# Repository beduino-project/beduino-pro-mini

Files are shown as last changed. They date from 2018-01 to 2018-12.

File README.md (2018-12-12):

Beduino Pro Mini
================

The Beduino Pro Mini is a prototyping board based on the NXP MKW41Z SoC:

* ARM Cortex-M0+ CPU
* 64/128 KB RAM
* 256/512 KB flash
* 2.4 GHz transceiver supporting Bluetooth Low Energy and IEEE 802.15.4
* AES-128 Hardware Accelerator
* True Random Number Generator

In addition to the SoC, the board features the following:

* 2.4 GHz trace antenna
* LDO voltage regulator for 5V supply
* The necessary oscillators and passive components
* Two LEDs (red and green)
* Reset button

The board layout also includes a DIPDAP programmer, which can be
detached from the Beduino Pro Mini (using a fine saw or a dremel tool)
and later reconnected using the usual seven-pin DIPDAP header.
The programmer features the following:

* USB connection
* Flashing and debugging of the MKW41Z using SWD
* Fully supported in OpenOCD
* USB-to-Serial adapter
* Powering of Beduino Pro Mini over USB

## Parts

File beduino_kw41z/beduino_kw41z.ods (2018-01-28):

Mouser | Tqnty | Ref | Qnty | Spare | Spconst | Value | Cmp name | Footprint | Description | Vendor
449-LFXTAL055295REEL | 19 | Y1, | 1 |  | 2 | 12MHz | Crystal_GND24 | Crystals:Crystal_SMD_3225-4pin_3.2x2.5mm | Four pin crystal (GND on pins 2 and 4), e.g. in SMD package
579-TC1017-3.3VLTTR | 36 | U1, U3, | 2 |  | 2 | TC1017 | TC1017 | TO_SOT_Packages_SMD:SOT-23-5 | 150mA Low Dropout Regulator with ERROR output in 5-Pin SOT-23 package
581-ST2012SB32E0HPWB | 18 | Y3, | 1 |  | 1 | 32KHz | Crystal | Crystals:Crystal_SMD_2012-2pin_2.0x1.2mm | Two pin crystal
603-RC0603JR-0710KL | 61 | R5, R4, R16, | 3 |  | 10 | 10k | R | Resistors_SMD:R_0603 | Resistor
603-RC0603JR-071K5L | 27 | R3, | 1 |  | 10 | 1k5 | R | Resistors_SMD:R_0603 | Resistor
603-RC0603JR-0733RL | 44 | R1, R2, | 2 |  | 10 | 33 | R | Resistors_SMD:R_0603 | Resistor
603-RC0603JR-07470RL | 180 | R9, R10, R11, R12, R13, R6, R7, R8, R14, R15, | 10 |  | 10 | 470 | R | Resistors_SMD:R_0603 | Resistor
604-APT1608EC | 44 | D2, D5, | 2 |  | 10 | Red | LED | LEDs:LED_0603 | LED generic
604-APT1608SGC | 44 | D4, D6, | 2 |  | 10 | Green | LED | LEDs:LED_0603 | LED generic
604-APT1608SYCK | 27 | D3, | 1 |  | 10 | Yellow | LED | LEDs:LED_0603 | LED generic
611-KMR621NGLFS | 35 | SW1, SW2, | 2 |  | 1 | SW_Push | SW_Push | button:SW_SPST_KMR6 | Push button switch, generic, two pins
726-BAT60AE6327HTSA1 | 53 | D1, D7, D8, | 3 |  | 2 | BAT60A | D_Schottky | Diodes_SMD:D_SOD-323 | Schottky diode
726-BSS84PH6327XTSA2 | 22 | Q1, | 1 |  | 5 | Q_PMOS_SGD | Q_PMOS_SGD | TO_SOT_Packages_SMD:SOT-23 | Transistor P-MOSFET with substrate diode (general)
771-LPC11U35FHI33501 | 17 | U2, | 1 |  |  | LPC11U35FHI33-501 | LPC11U35FHI33-501 | Housings_DFN_QFN:QFN-32-1EP_5x5mm_Pitch0.5mm
774-402F32011CAR | 18 | Y2, | 1 |  | 1 | 32MHz | Crystal_GND24 | Crystals:Crystal_SMD_2016-4pin_2.0x1.6mm | Four pin crystal (GND on pins 2 and 4), e.g. in SMD package
798-ZX62D-B-5PA830 | 17 | J1, | 1 |  |  | USB_OTG | USB_OTG | Connectors:USB_Micro-B | USB mini/micro connector
80-C0603C104K8RAC | 61 | C6, C8, C13, | 3 |  | 10 | 100n | C | Capacitors_SMD:C_0603 | Unpolarized capacitor
80-C0603C105Z8V | 44 | C1, C9, | 2 |  | 10 | 1u | C | Capacitors_SMD:C_0603 | Unpolarized capacitor
80-C0603C180J5G | 44 | C5, C7, | 2 |  | 10 | 18p | C_Small | Capacitors_SMD:C_0603 | Unpolarized capacitor
81-GRM1555C1HR70CA1D | 44 | C10, C11, | 2 |  | 10 | 0.7p | C | Capacitors_SMD:C_0402 | Unpolarized capacitor
81-GRM155R61H104KE9D | 78 | C14, C15, C16, C17, | 4 |  | 10 | 100n | C | Capacitors_SMD:C_0402 | Unpolarized capacitor
81-LQG15HZ5N1S02D | 27 | L1, | 1 |  | 10 | 5.1n | L | Inductors_SMD:L_0402 | Inductor
841-MKW41Z256VHT4 | 17 | U5, | 1 |  |  | MKW41Z | MKW41Z | Housings_DFN_QFN:QFN-48-1EP_7x7mm_Pitch0.5mm | NXP MKW41Z Microcontroller
963-JMK107ABJ106MA-T | 44 | C4, C12, | 2 |  | 10 | 10u | C | Capacitors_SMD:C_0603 | Unpolarized capacitor
 | 34 | J2, J3, | 2 |  |  | Conn_01x07 | Conn_01x07 | Pin_Headers:Pin_Header_Straight_1x07_Pitch2.54mm | Generic connector, single row, 01x07
 | 17 | U4, | 1 |  |  | Module_CONN | Module_CONN | Arduino_Mini

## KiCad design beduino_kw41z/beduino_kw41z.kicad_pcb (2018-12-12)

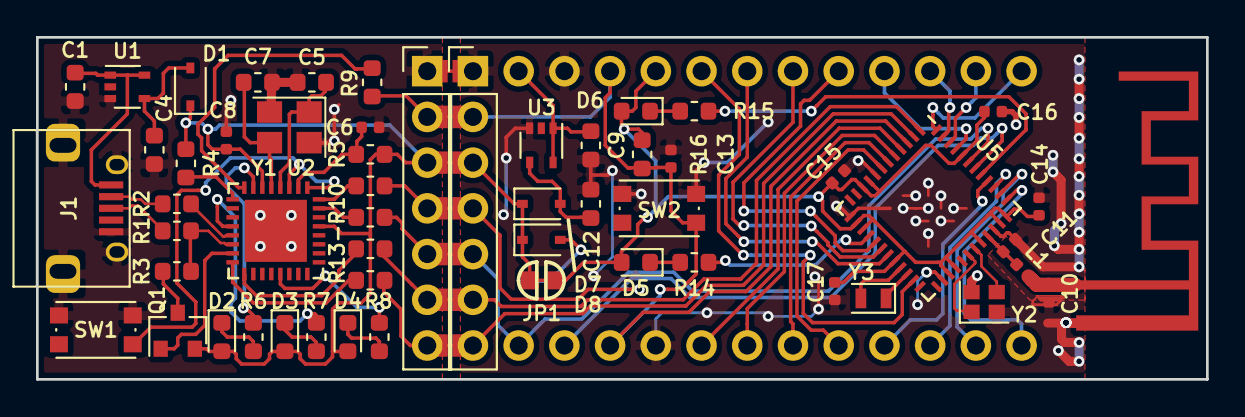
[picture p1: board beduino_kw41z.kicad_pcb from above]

Board: 2 copper layers, 65.0 x 19.0 mm, 57 parts (1 on the bottom side), 60 nets.

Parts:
ANT1: SWRA117D
BT1: Battery_Cell; Keystone_1058_1x2032-CoinCell
C1, C9: 1u; C_0603_1608Metric
C4, C12: 10u; C_0603_1608Metric
C5, C7: 18p; C_0603_1608Metric
C6, C8, C13, C14, C15, C16, C17: 100n; C_0402_1005Metric
C10, C11: 0.7p; C_0402_1005Metric
D1, D7, D8: BAT60A; D_SOD-323
D2, D5: Red; LED_0603_1608Metric
D3: Yellow; LED_0603_1608Metric
D4, D6: Green; LED_0603_1608Metric
J1: USB_OTG; USB_Micro-B
J2, J3: Conn_01x07; Pin_Header_Straight_1x07_Pitch2.54mm
JP1: Power; SOLDER-JUMPER_1-WAY
L1: 5.1n; L_0402_1005Metric
Q1: Q_PMOS_GSD; SOT-23
R1, R2: 33; R_0603_1608Metric
R3: 1k5; R_0603_1608Metric
R4, R5, R16: 10k; R_0603_1608Metric
R6, R7, R8, R9, R10, R11, R13, R13-R10, R14, R15: 470; R_0603_1608Metric
SW1: SW_Push; SW_SPST_KMR2
SW2: Reset; SW_SPST_KMR2
U1, U3: TC1017; SOT-353_SC-70-5
U2: LPC11U35FHI33-501; QFN-32-1EP_5x5mm_P0.5mm_EP3.45x3.45mm
U4: Module_CONN; Arduino_Mini
U5: MKW41Z; QFN-48-1EP_7x7mm_P0.5mm_EP5.15x5.15mm
Y1: 12MHz; Crystal_SMD_3225-4Pin_3.2x2.5mm
Y2: 32MHz; Crystal_SMD_2016-4Pin_2.0x1.6mm
Y3: 32KHz; Crystal_SMD_2012-2Pin_2.0x1.2mm

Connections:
+3V3: C8.1, C14.1, C15.1, C16.1, C17.1, D1.1, D2.2, D3.2, D4.2, D5.2, D6.2, D7.1, D8.1, J2.3, J3.3, JP1.1, JP1.2, Q1.2, R4.1, R5.2, R16.1, U2.6, U2.29, U4.21, U5.9, U5.10, U5.14, U5.15, U5.20, U5.27, U5.28, U5.32, U5.35, U5.36, U5.44
/DIPDAP/TGT_NRESET: C13.1, J2.2, J3.2, R9.1, R16.2, SW2.2, U4.3, U4.22, U5.3
/DIPDAP/TGT_RX: J2.4, J3.4, R10.1, U4.2, U5.42
/DIPDAP/TGT_SWCLK: J2.7, J3.7, R13.1, U5.2
/DIPDAP/TGT_SWDIO: J2.6, J3.6, R13-R10.1, U5.1
/DIPDAP/TGT_TX: J2.5, J3.5, R11.1, U4.1, U5.43
/KW41Z/A0: U4.17, U5.17
/KW41Z/A1: U4.18, U5.18
/KW41Z/A2: U4.19, U5.19
/KW41Z/A3: U4.20, U5.23
/KW41Z/ANT: C11.1, L1.1, U5.33
/KW41Z/D2: U4.5, U5.4
/KW41Z/D3: U4.6, U5.5
/KW41Z/D4: U4.7, U5.6
/KW41Z/D5: U4.8, U5.7
/KW41Z/D6: U4.9, U5.40
/KW41Z/D9: U4.12, U5.37
/KW41Z/D10: U4.13, U5.48
/KW41Z/LED_Green: R15.1, U5.41
/KW41Z/LED_Red: R14.1, U5.16
/KW41Z/MISO: U4.15, U5.47
/KW41Z/MOSI: U4.14, U5.46
/KW41Z/SCK: U4.16, U5.45
/KW41Z/SCL: U4.11, U5.38
/KW41Z/SDA: U4.10, U5.39
GND: ANT1.2, BT1.2, C1.2, C4.2, C5.2, C6.2, C7.2, C8.2, C9.2, C10.2, C11.2, C12.2, C13.2, C14.2, C15.2, C16.2, C17.2, J1.5, J1.6, J2.1, J3.1, SW1.1, SW2.1, U1.3, U2.33, U3.3, U4.4, U4.23, U5.8, U5.13, U5.26, U5.34, Y1.2, Y1.4, Y2.2, Y2.4
unnamed: ANT1.1, C10.1, L1.2
unnamed: BT1.1, D8.2
unnamed: R2.1, U2.13
unnamed: R1.1, R3.1, U2.14
unnamed: C4.1, D1.2, U1.4
unnamed: C5.1, U2.4, Y1.1
unnamed: C6.1, R5.1, U2.2
unnamed: C7.1, U2.5, Y1.3
unnamed: C12.1, D7.2, U3.4
unnamed: D2.1, R6.1
unnamed: D3.1, R7.1
unnamed: D4.1, R8.1
unnamed: D5.1, R14.2
unnamed: D6.1, R15.2
unnamed: J1.2, R2.2
unnamed: J1.3, R1.2
unnamed: Q1.1, U2.15
unnamed: Q1.3, R3.2
unnamed: R4.2, U2.9
unnamed: R6.2, U2.7
unnamed: R7.2, U2.12
unnamed: R8.2, U2.21
unnamed: R9.2, U2.8
unnamed: R10.2, U2.32
unnamed: R11.2, U2.31
unnamed: R13-R10.2, U2.17
unnamed: R13.2, U2.16
unnamed: SW1.2, U2.1, U2.3
unnamed: U5.21, Y3.2
unnamed: U5.22, Y3.1
unnamed: U5.30, Y2.1
unnamed: U5.31, Y2.3
VBUS: C1.1, J1.1, U1.1, U1.5
VCC: C9.1, U3.1, U3.5, U4.24

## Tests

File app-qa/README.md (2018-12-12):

This is an application for [RIOT][] that helps with post-production
quality assurance.

Documentation for this has not yet been written, sadly.
I promise to write documentation as soon as I know of someone ordering
these boards.

[RIOT]: http://riot-os.org/
	"The friendly Operating System for the Internet of Things."

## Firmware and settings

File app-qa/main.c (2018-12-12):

/*
 * Copyright (C) 2018 Tristan Bruns
 *
 * Licensed under the Apache License, Version 2.0 (the "License");
 * you may not use this file except in compliance with the License.
 * You may obtain a copy of the License at
 *
 *     http://www.apache.org/licenses/LICENSE-2.0
 *
 * Unless required by applicable law or agreed to in writing, software
 * distributed under the License is distributed on an "AS IS" BASIS,
 * WITHOUT WARRANTIES OR CONDITIONS OF ANY KIND, either express or implied.
 * See the License for the specific language governing permissions and
 * limitations under the License.
 */

#include <stdio.h>

#include "board.h"
#include "periph/gpio.h"

#include "xtimer.h"

gpio_t gpios[] = {
  // back row, left to right
  GPIO_PIN(PORT_B, 18),
  GPIO_PIN(PORT_B,  3),
  GPIO_PIN(PORT_B,  2),
  GPIO_PIN(PORT_B,  1),
  GPIO_PIN(PORT_C, 16),
  GPIO_PIN(PORT_C, 17),
  GPIO_PIN(PORT_C, 18),
  GPIO_PIN(PORT_C, 19),
  // front row, left to right
  GPIO_PIN(PORT_A, 16),
  GPIO_PIN(PORT_A, 17),
  GPIO_PIN(PORT_A, 18),
  GPIO_PIN(PORT_A, 19),
  GPIO_PIN(PORT_C, 4),
  GPIO_PIN(PORT_C, 3),
  GPIO_PIN(PORT_C, 2),
  GPIO_PIN(PORT_C, 1),
};
#define NUM_GPIOS (sizeof gpios / sizeof gpios[0])

#ifdef CLOCK_CORECLOCK
#define DELAY_SHORT         (CLOCK_CORECLOCK / 50)
#else
#define DELAY_SHORT         (500000UL)
#endif

void dumb_delay(uint32_t delay)
{
    for (uint32_t i = 0; i < delay; i++) {
        __asm__("nop");
    }
}

//! Signal test FAIL to human
void fail(void)
{
    while (1) {
        LED0_TOGGLE;
        dumb_delay(DELAY_SHORT);
        //xtimer_usleep(100);
    }
}

//! Signal test pass to human
void pass(void)
{
    while (1) {
        LED1_TOGGLE;
        dumb_delay(DELAY_SHORT);
    }
}

//! Flash LEDs for testing
void led_test(void)
{
    int i;

    for (i = 0; i < 10; i++) {
        LED0_TOGGLE;
        LED1_TOGGLE;
        dumb_delay(DELAY_SHORT);
    }
}

//! Check for ground shorts
void check_short_gnd(void)
{
    unsigned int i;

    for (i = 0; i < NUM_GPIOS; i++)
    {
        gpio_init(gpios[i], GPIO_IN_PU);
    }
    dumb_delay(DELAY_SHORT); // allow for pin capacitance
    for (i = 0; i < NUM_GPIOS; i++)
    {
        if (!gpio_read(gpios[i]))
            fail();
    }
}

//! Check for supply shorts
void check_short_vcc(void)
{
    unsigned int i;

    for (i = 0; i < NUM_GPIOS; i++)
    {
        gpio_init(gpios[i], GPIO_IN_PD);
    }
    dumb_delay(DELAY_SHORT); // allow for pin capacitance
    for (i = 0; i < NUM_GPIOS; i++)
    {
        if (gpio_read(gpios[i]))
            fail();
    }
}

//! Check for shorts between gpios
// This test configures GPIOs as outputs. Try to make sure this is safe
// beforehand!
void check_short_gpio(void)
{
    unsigned int i, j;

    // configure all GPIOs as inputs with pulldown
    for (i = 0; i < NUM_GPIOS; i++)
    {
        gpio_init(gpios[i], GPIO_IN_PD);
    }

    // drive each pin HIGH and check all other pins are still LOW
    for (i = 0; i < NUM_GPIOS; i++)
    {
        gpio_init(gpios[i], GPIO_OUT);
        gpio_set(gpios[i]);
        dumb_delay(DELAY_SHORT); // allow for pin capacitance

        for (j = 0; j < NUM_GPIOS; j++) {
            if (j != i && gpio_read(gpios[j])) {
                // stop driving the pin because it might be shorted to
                // other stuff, too. but use a pullup so the pin can be
                // found with a multimeter if it isn't.
                gpio_init(gpios[i], GPIO_IN_PU);

                fail();
            }
        }
        gpio_init(gpios[i], GPIO_IN_PD);
    }
}

//! Check for unconnected pads
// This needs user interaction.
void check_unconnected(void)
{
    // what am I even doing?
    unsigned int i;
    char state[NUM_GPIOS + 1];

    state[NUM_GPIOS] = '\0'; // tease the compiler

    for (i = 0; i < NUM_GPIOS; i++)
    {
        state[i] = '?';
        gpio_init(gpios[i], GPIO_IN_PD);
    }
    dumb_delay(DELAY_SHORT); // allow for pin capacitance

    puts("Gently pull up all GPIOs with TODO \\Ohms");
    printf("Status: %s\n", state);

    int cont = 1;
    while (cont) {
        cont = 0;
        for (i = 0; i < NUM_GPIOS; i++)
        {
            if (state[i] != '?')
                continue;
            cont = 1;

            if (gpio_read(gpios[i])) {
                state[i] = '+';
                printf("Status: %s\n", state);
            }
        }
    }

    puts("\nPass.");
}

void check_xtimer(void)
{
    uint32_t diff;
    volatile xtimer_ticks32_t a, b;

    a = xtimer_now();
    dumb_delay(DELAY_SHORT);
    b = xtimer_now();

    diff = xtimer_usec_from_ticks(xtimer_diff(b, a));

    if (diff < 139587 - 1000 || 139587 + 1000 < diff) {
        printf("xtimer test failed: %lu\n", diff);
        fail();
    }
}

int main(void)
{
    puts("Welcome to Beduino Pro Mini QA test app");

    led_test();
    check_xtimer();
    check_short_gnd();
    check_short_vcc();
    check_short_gpio();
    check_unconnected();

    pass();

    return 0;
}

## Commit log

2017-12-03 Add gitignore for kicad files
2017-12-03 Add schematic files for the pcb and the created libraries.
    [beduino_kw41z.kicad_pcb, beduino_kw41z.sch, dipdap.sch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]
2017-12-03 Add antenna libraries and antenna hardware design.
2017-12-04 Add jumper into the power trace.
    This makes it possible to measure the current used by the module.
    [kw41z.sch]
2017-12-04 Change 32MHz Crystal to a 4 pin type.
    [kw41z.sch]
2017-12-12 Update schematic for new KiCAD version.
    Also add some components.
    [beduino_kw41z.sch, dipdap.sch, kw41z.sch]
2017-12-12 Add initial component placement.
    [beduino_kw41z.kicad_pcb]
2017-12-12 Add some initial routing ideas.
    [beduino_kw41z.kicad_pcb]
2017-12-12 Some more PCB design work.
    [beduino_kw41z.kicad_pcb]
2017-12-16 Small changes in the schematics.
    [dipdap.sch, kw41z.sch]
2017-12-16 Finished routing. Needs checking.
    [beduino_kw41z.kicad_pcb]
2017-12-18 Move some traces to improve the design a bit.
    [beduino_kw41z.kicad_pcb]
2017-12-21 Small improvements to the PCB design.
    [beduino_kw41z.kicad_pcb]
2018-01-23 Add panelized pcb
    [beduino_kw41z.kicad_pcb, beduino_kw41z_multi.kicad_pcb]
2018-01-26 add BOM with mouser part numbers
    [beduino_kw41z.ods]
2018-01-28 updated to mouser cart 28.01.2018 11:55:35
    [beduino_kw41z.ods]
2018-02-26 Fix board design errors.
    This also migrates the files back to the kicad v4 file format. Otherwise
    everyone would need to build kicad from git.
    [beduino_kw41z.kicad_pcb, beduino_kw41z.sch, dipdap.sch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]
2018-03-16 Update board design to be kicad v4 compatible again.
    [beduino_kw41z.kicad_pcb]
2018-03-16 Update multi pcb design to be kicad v4 compatible.
    [beduino_kw41z_multi.kicad_pcb]
2018-12-09 Update PCB layout.
    The connection between the dipdap and the kw41z-mini is now closed with
    a small trace. If the trace is cut, added smd pads simplify the creation
    of solder jumpers.
    [beduino_kw41z.kicad_pcb, beduino_kw41z.sch, beduino_kw41z_multi.kicad_pcb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]
2018-12-09 Add original schematic and pcb layout for the kw41z-mini.
    Also add pinout diagram for the swd socket.
    [kw41z-mini-r1rc1.sch]
2018-12-12 Add license informations.
    [beduino_kw41z.kicad_pcb, beduino_kw41z.sch]
2018-12-12 Remove unused stuff.
    [beduino_kw41z.kicad_pcb, beduino_kw41z_panel.kicad_pcb, dipdap.sch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]

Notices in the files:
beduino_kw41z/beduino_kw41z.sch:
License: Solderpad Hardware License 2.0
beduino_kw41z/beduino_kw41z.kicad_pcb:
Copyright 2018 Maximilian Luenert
